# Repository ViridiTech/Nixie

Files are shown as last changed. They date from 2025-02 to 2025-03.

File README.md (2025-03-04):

# Nixie
 4 digit nixie clock on IN-12 lamps
 
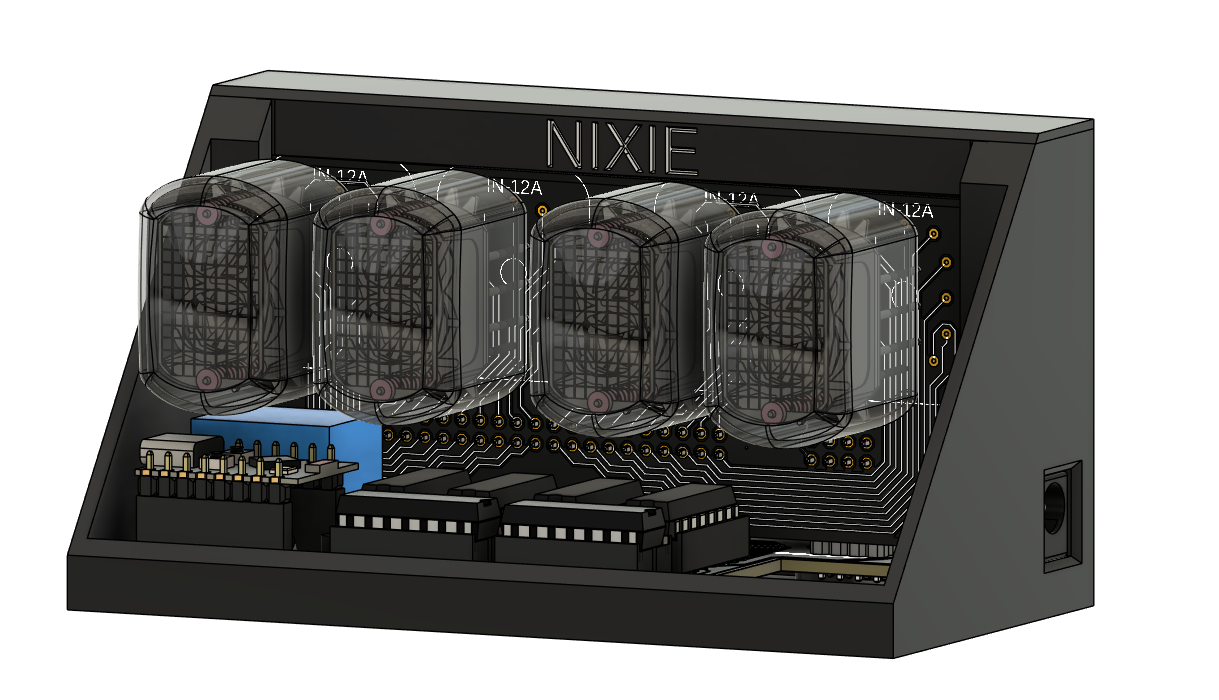
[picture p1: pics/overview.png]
</a>

General schematic inculed most important components:

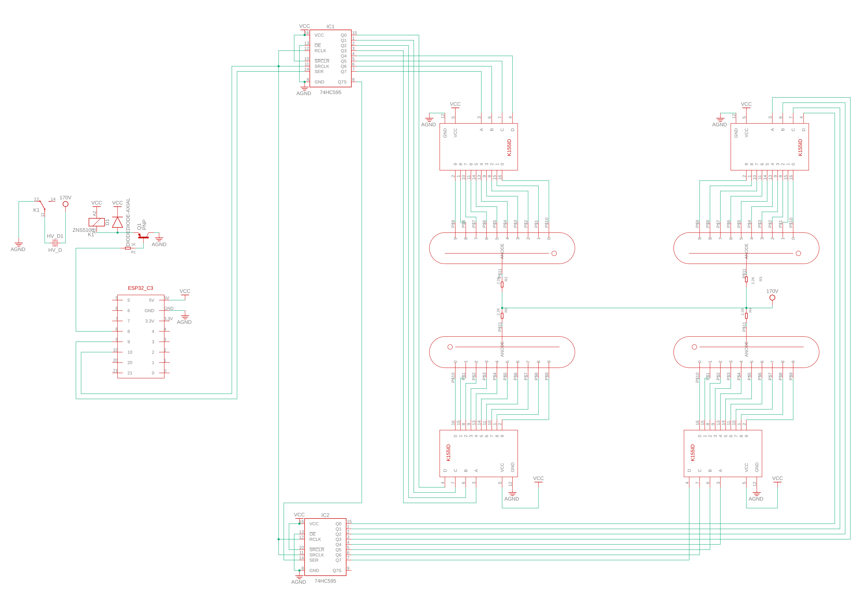
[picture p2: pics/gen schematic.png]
</a>

Brain of the clock is [ESP32-C3 Super Mini](https://allegro.pl/events/clicks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).

ICs used:

- two 74HC959 shift registers,

- four nixie lamp drivers: K155ID1 and SN74141N both work the same and have the same I/O.

Four IN-12 display time. Both A and B variants could be used.

Seconds indicator is taken from probe screwdriver, typical neon indicator (gas-discharge lamp) can be used.

Seconds indicator is driven by 5V relay (transistor-diode control to ensure no damage to microcontroler should be used, or alternatively for DIY solution Arduino relay module can be used).

Nixie lamps require 170V power supply to be used, I chose [this one](https://pl.aliexpress.com/item/1005005721193065.html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).

# IMPORTANT
You have to program ESP32 yourself using Arduino IDE or other ESP-compatible environment using NIXIE_clock directory.

In the code you MUST MODIFY WiFi settings to allow the clock to connect to the Internet.

# DISCLAIMER
The current code has not been tested on current version of hardware.

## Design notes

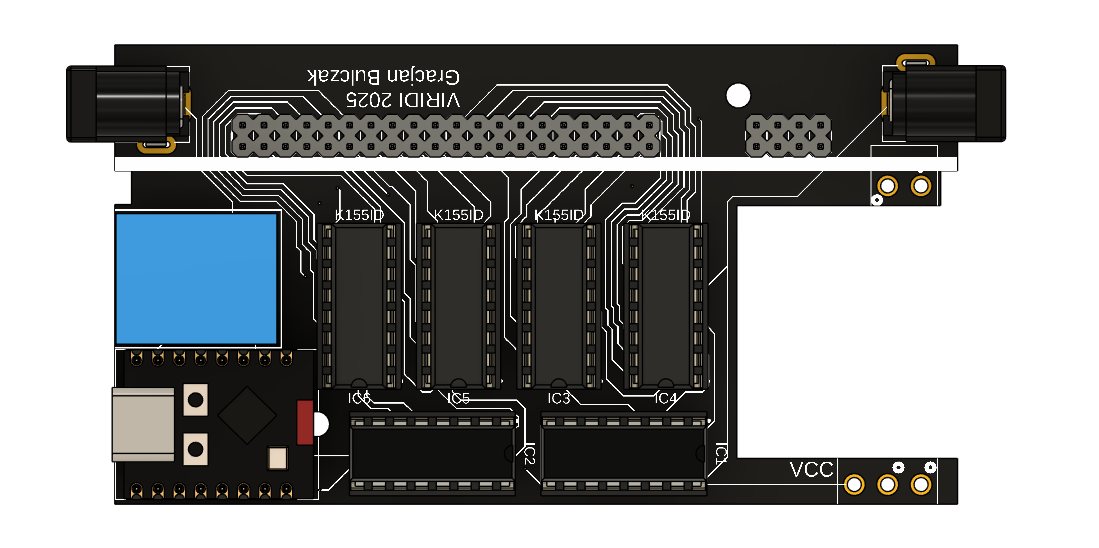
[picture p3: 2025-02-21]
pics/base.png

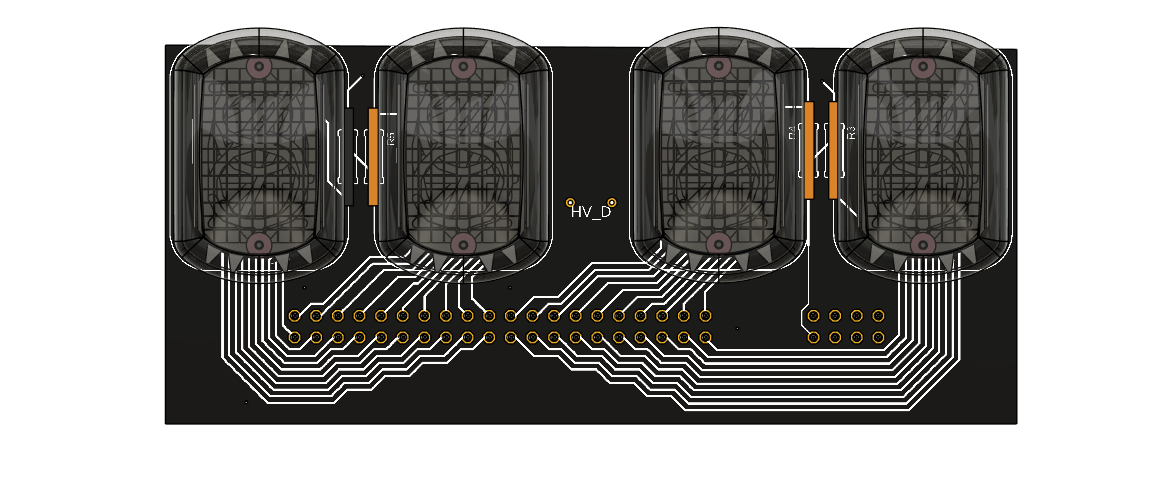
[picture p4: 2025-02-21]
pics/display.png

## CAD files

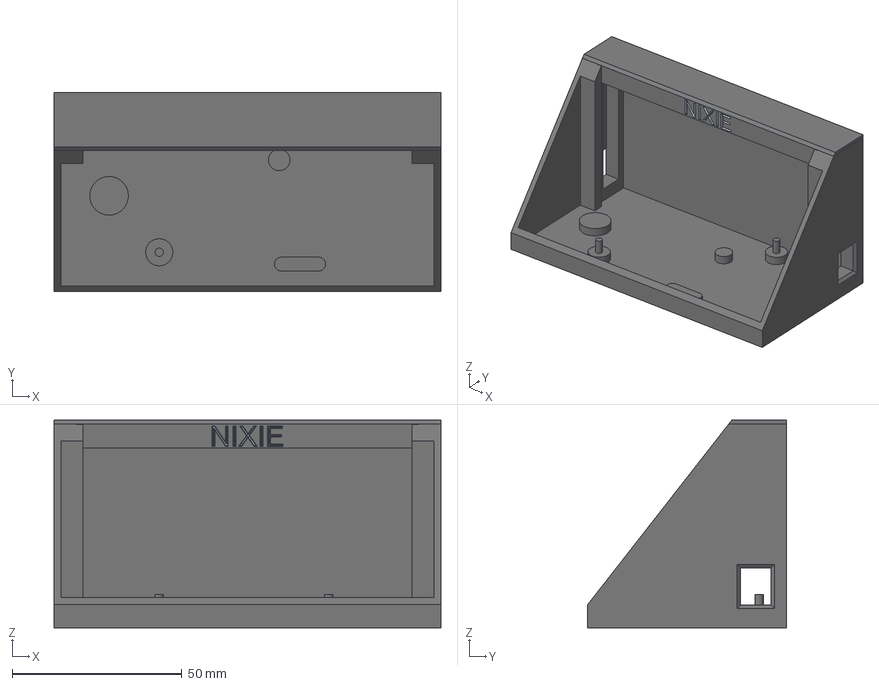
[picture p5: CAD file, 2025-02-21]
Case.3mf
114.0 x 58.5 x 61.2 mm

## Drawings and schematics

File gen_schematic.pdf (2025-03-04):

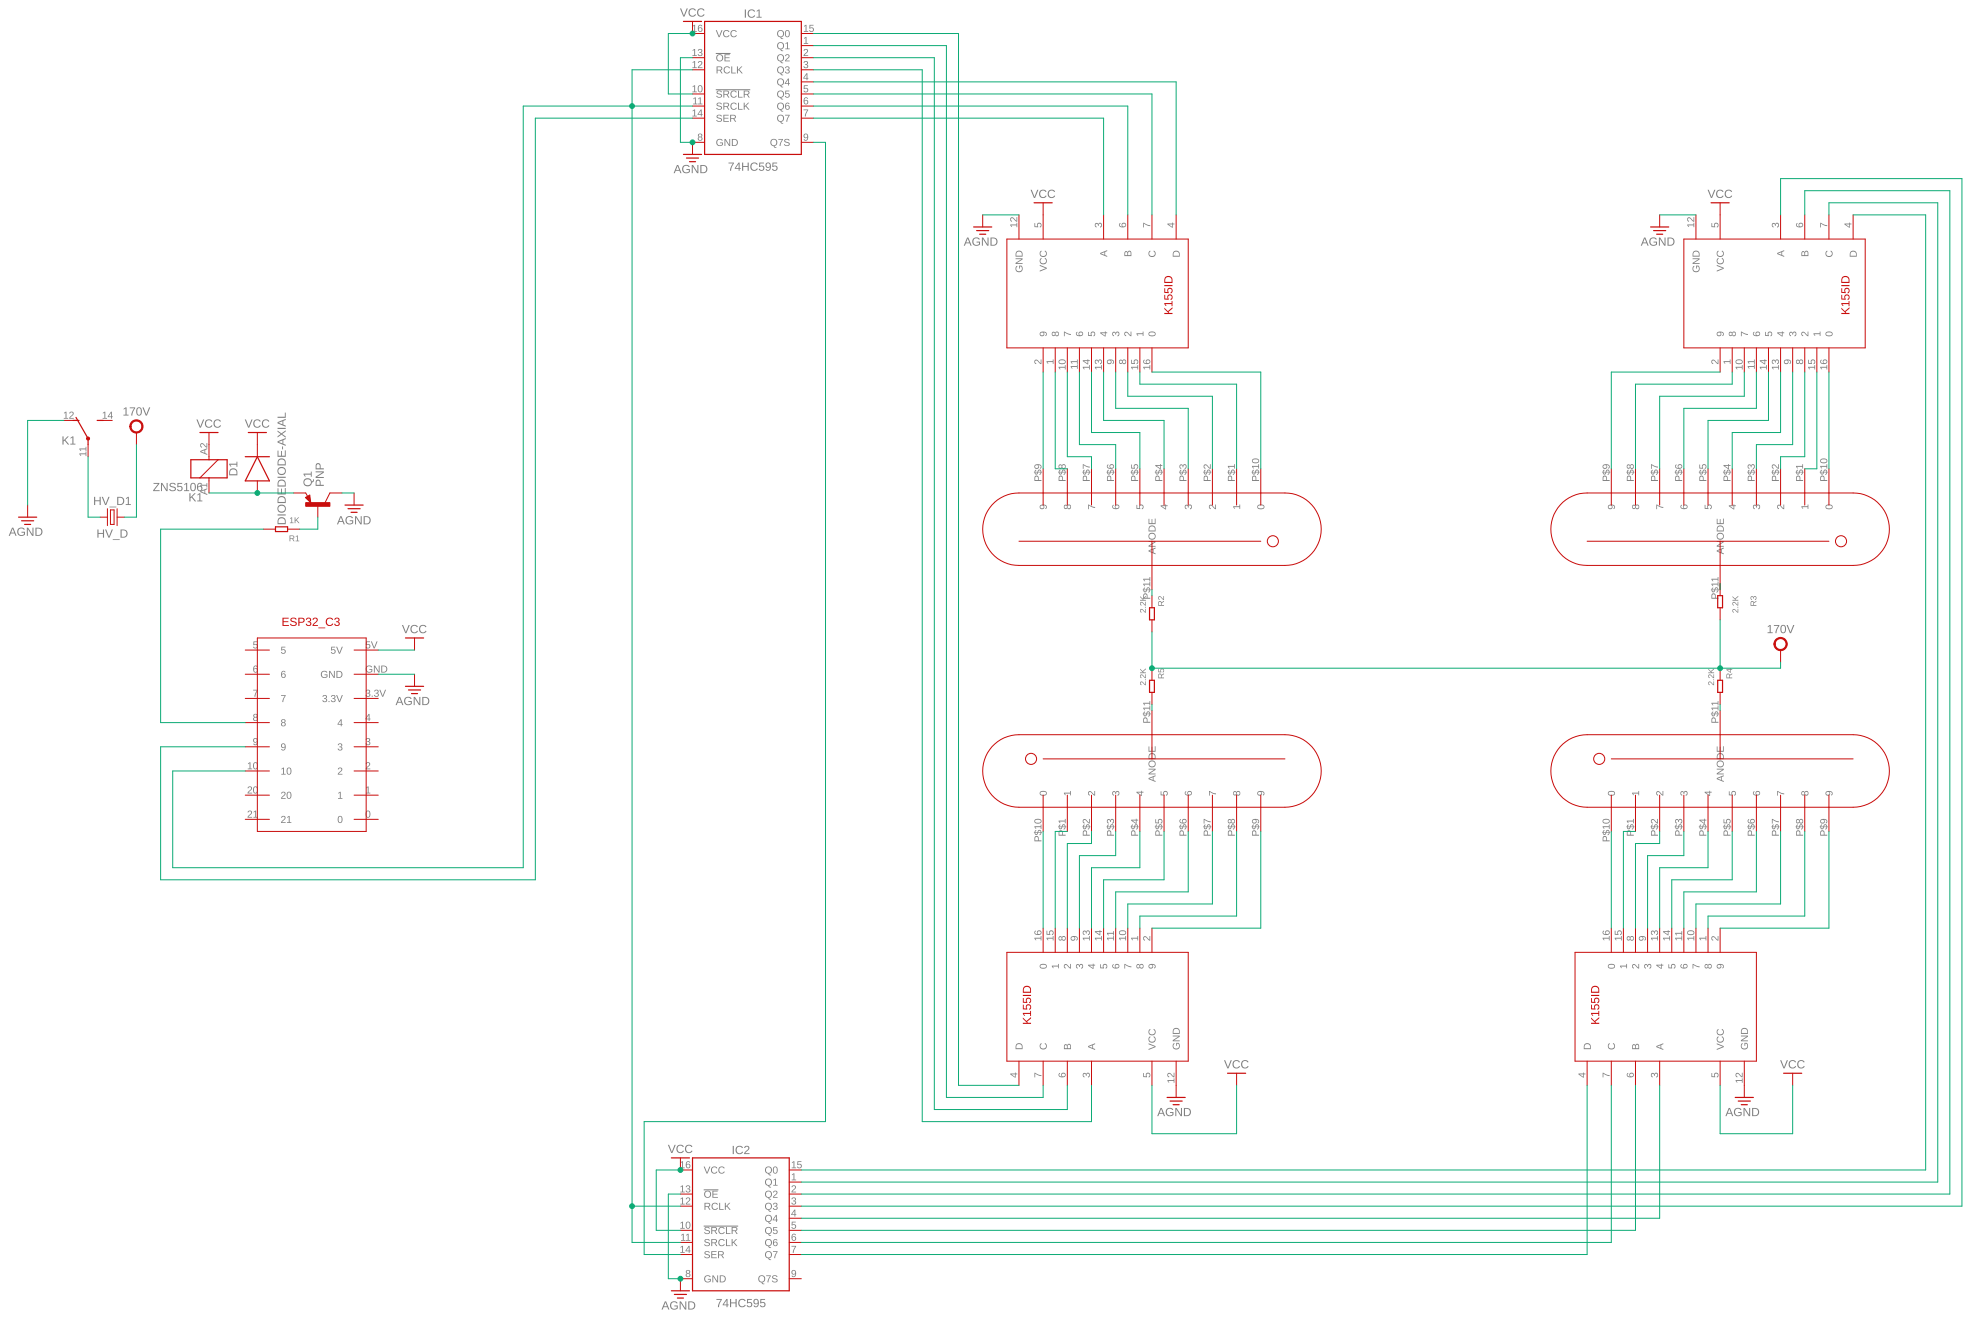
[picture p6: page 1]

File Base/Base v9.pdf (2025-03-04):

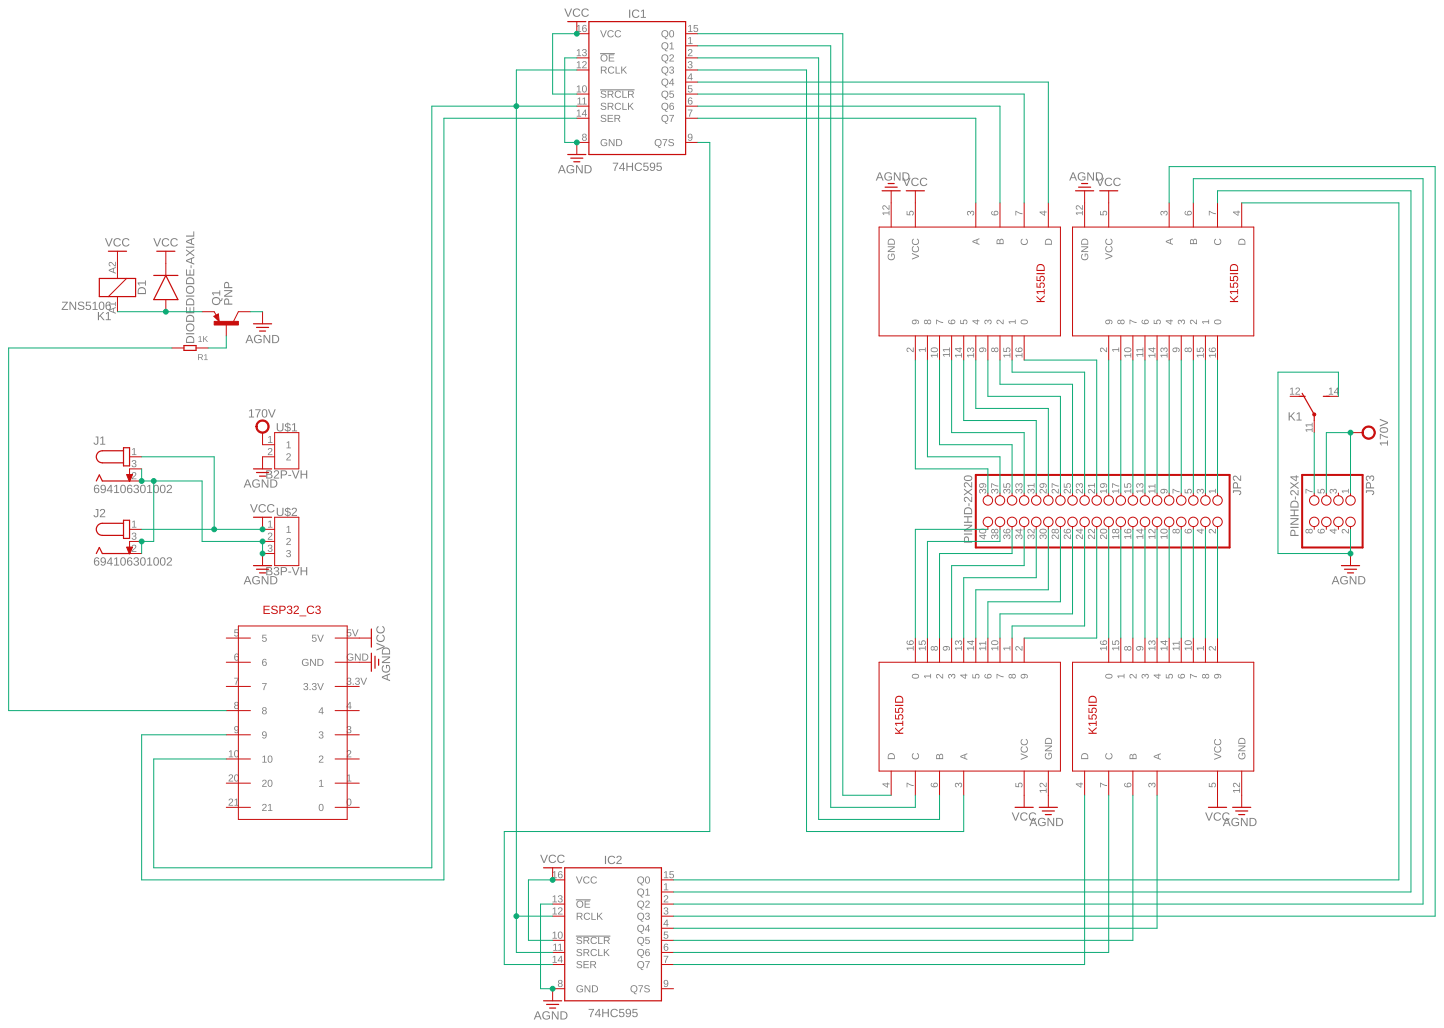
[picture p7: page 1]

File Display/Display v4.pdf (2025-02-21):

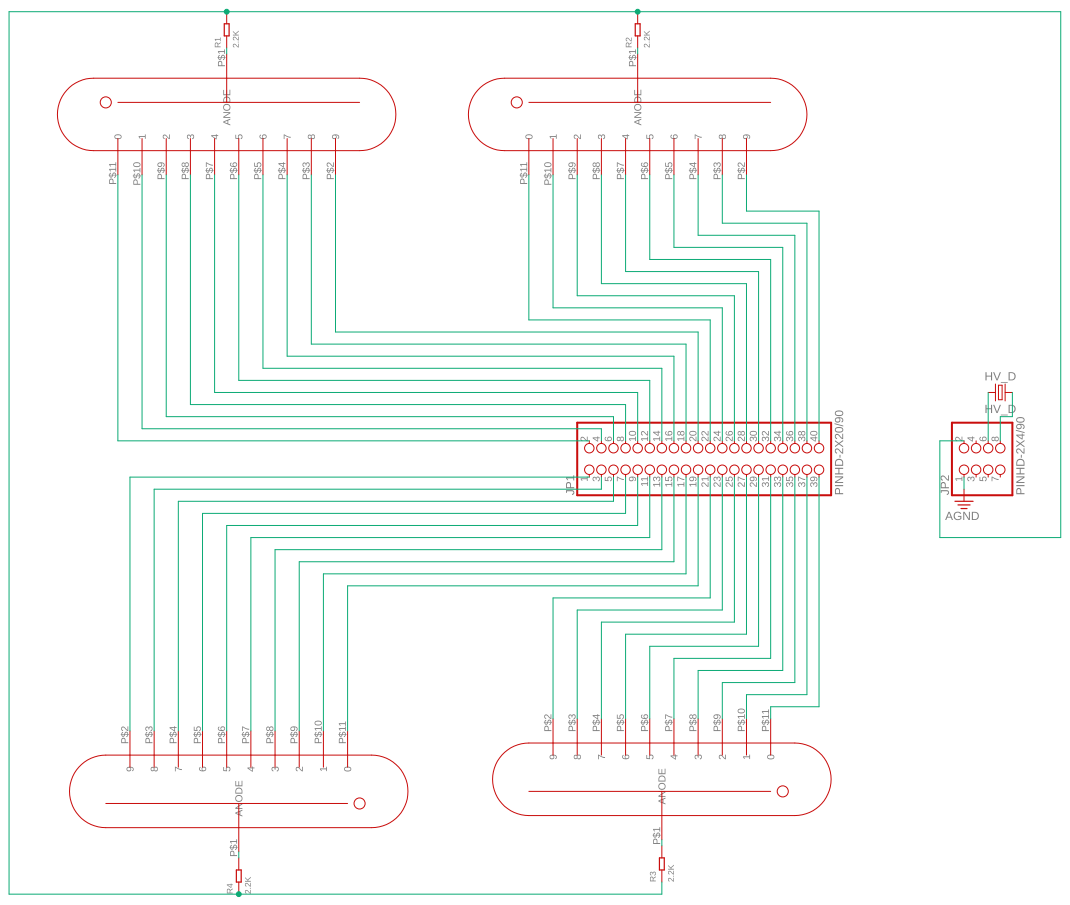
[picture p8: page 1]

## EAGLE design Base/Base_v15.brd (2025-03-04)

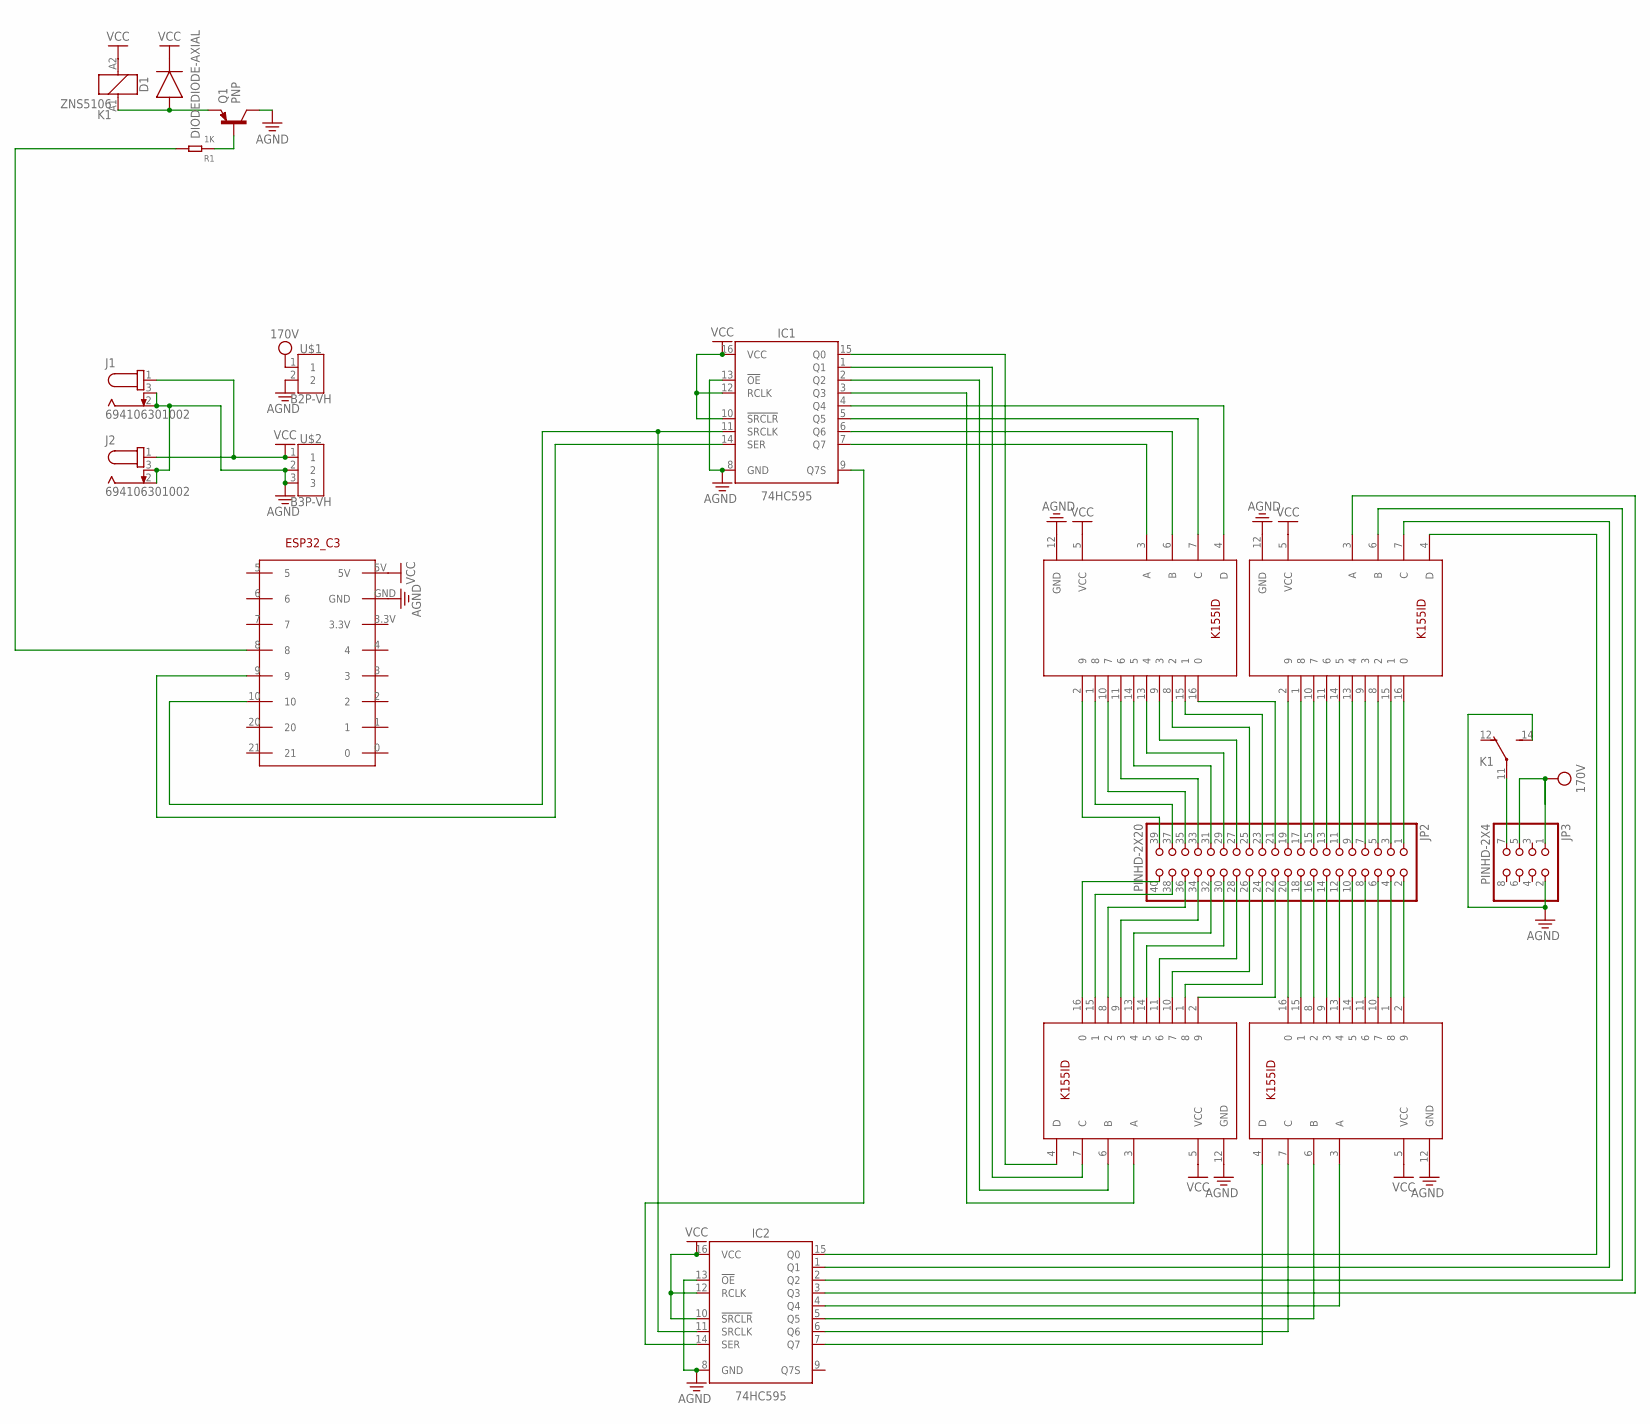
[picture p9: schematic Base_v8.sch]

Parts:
D1: DIODEDIODE-AXIAL; DIODE-AXIAL
IC1, IC2: 74HC595; DIP762W53P254L1969H508Q16B
IC3, IC4, IC5, IC6: K155ID
J1, J2: 694106301002
JP2: PINHD-2X20; 2X20
JP3: PINHD-2X4; 2X04
K1: ZNS5106; ZN5
Q1: PNP; TO92
R1: 1K; PR-D2.3XL6.5MM
U$1: B2P-VH; B2P-VH_396-2N
U$2: B3P-VH; B3P-VH_396_3N
U$5: ESP32_C3_SUPERMINI

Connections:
170V: JP3.1, JP3.5, U$1.1
AGND: IC1.8 (GND), IC1.13 (!OE), IC2.8 (GND), IC2.13 (!OE), IC3.12 (GND), IC4.12 (GND), IC5.12 (GND), IC6.12 (GND), J1.2, J1.3, J2.2, J2.3, JP3.2, K1.14 (S), Q1.1 (C), U$1.2, U$2.2, U$2.3, U$5.GND
unnamed: IC5.16 (0), JP2.1
unnamed: IC5.15 (1), JP2.3
unnamed: IC5.8 (2), JP2.5
unnamed: IC5.9 (3), JP2.7
unnamed: IC5.13 (4), JP2.9
unnamed: IC5.14 (5), JP2.11
unnamed: IC5.11 (6), JP2.13
unnamed: IC5.10 (7), JP2.15
unnamed: IC5.1 (8), JP2.17
unnamed: IC5.2 (9), JP2.19
unnamed: IC3.16 (0), JP2.21
unnamed: IC3.15 (1), JP2.23
unnamed: IC3.8 (2), JP2.25
unnamed: IC3.9 (3), JP2.27
unnamed: IC3.13 (4), JP2.29
unnamed: IC3.14 (5), JP2.31
unnamed: IC3.11 (6), JP2.33
unnamed: IC3.10 (7), JP2.35
unnamed: IC3.1 (8), JP2.37
unnamed: IC3.2 (9), JP2.39
unnamed: IC6.2 (9), JP2.2
unnamed: IC6.1 (8), JP2.4
unnamed: IC6.10 (7), JP2.6
unnamed: IC6.11 (6), JP2.8
unnamed: IC6.14 (5), JP2.10
unnamed: IC6.13 (4), JP2.12
unnamed: IC6.9 (3), JP2.14
unnamed: IC6.8 (2), JP2.16
unnamed: IC6.15 (1), JP2.18
unnamed: IC6.16 (0), JP2.20
unnamed: IC4.16 (0), JP2.40
unnamed: IC4.15 (1), JP2.38
unnamed: IC4.8 (2), JP2.36
unnamed: IC4.9 (3), JP2.34
unnamed: IC4.13 (4), JP2.32
unnamed: IC4.14 (5), JP2.30
unnamed: IC4.11 (6), JP2.28
unnamed: IC4.10 (7), JP2.26
unnamed: IC4.1 (8), JP2.24
unnamed: IC4.2 (9), JP2.22
unnamed: IC1.15 (Q0), IC4.4 (D)
unnamed: IC1.1 (Q1), IC4.7 (C)
unnamed: IC1.2 (Q2), IC4.6 (B)
unnamed: IC1.3 (Q3), IC4.3 (A)
unnamed: IC2.4 (Q4), IC6.3 (A)
unnamed: IC2.5 (Q5), IC6.6 (B)
unnamed: IC2.6 (Q6), IC6.7 (C)
unnamed: IC2.7 (Q7), IC6.4 (D)
unnamed: IC1.7 (Q7), IC3.3 (A)
unnamed: IC1.6 (Q6), IC3.6 (B)
unnamed: IC1.5 (Q5), IC3.7 (C)
unnamed: IC1.4 (Q4), IC3.4 (D)
unnamed: IC2.15 (Q0), IC5.4 (D)
unnamed: IC2.1 (Q1), IC5.7 (C)
unnamed: IC2.2 (Q2), IC5.6 (B)
unnamed: IC2.3 (Q3), IC5.3 (A)
unnamed: IC1.9 (Q7S), IC2.14 (SER)
unnamed: IC1.14 (SER), U$5.9
unnamed: D1.1 (A), K1.A1 (1), Q1.3 (E)
unnamed: Q1.2 (B), R1.1
unnamed: R1.2, U$5.8
unnamed: JP3.7, K1.11

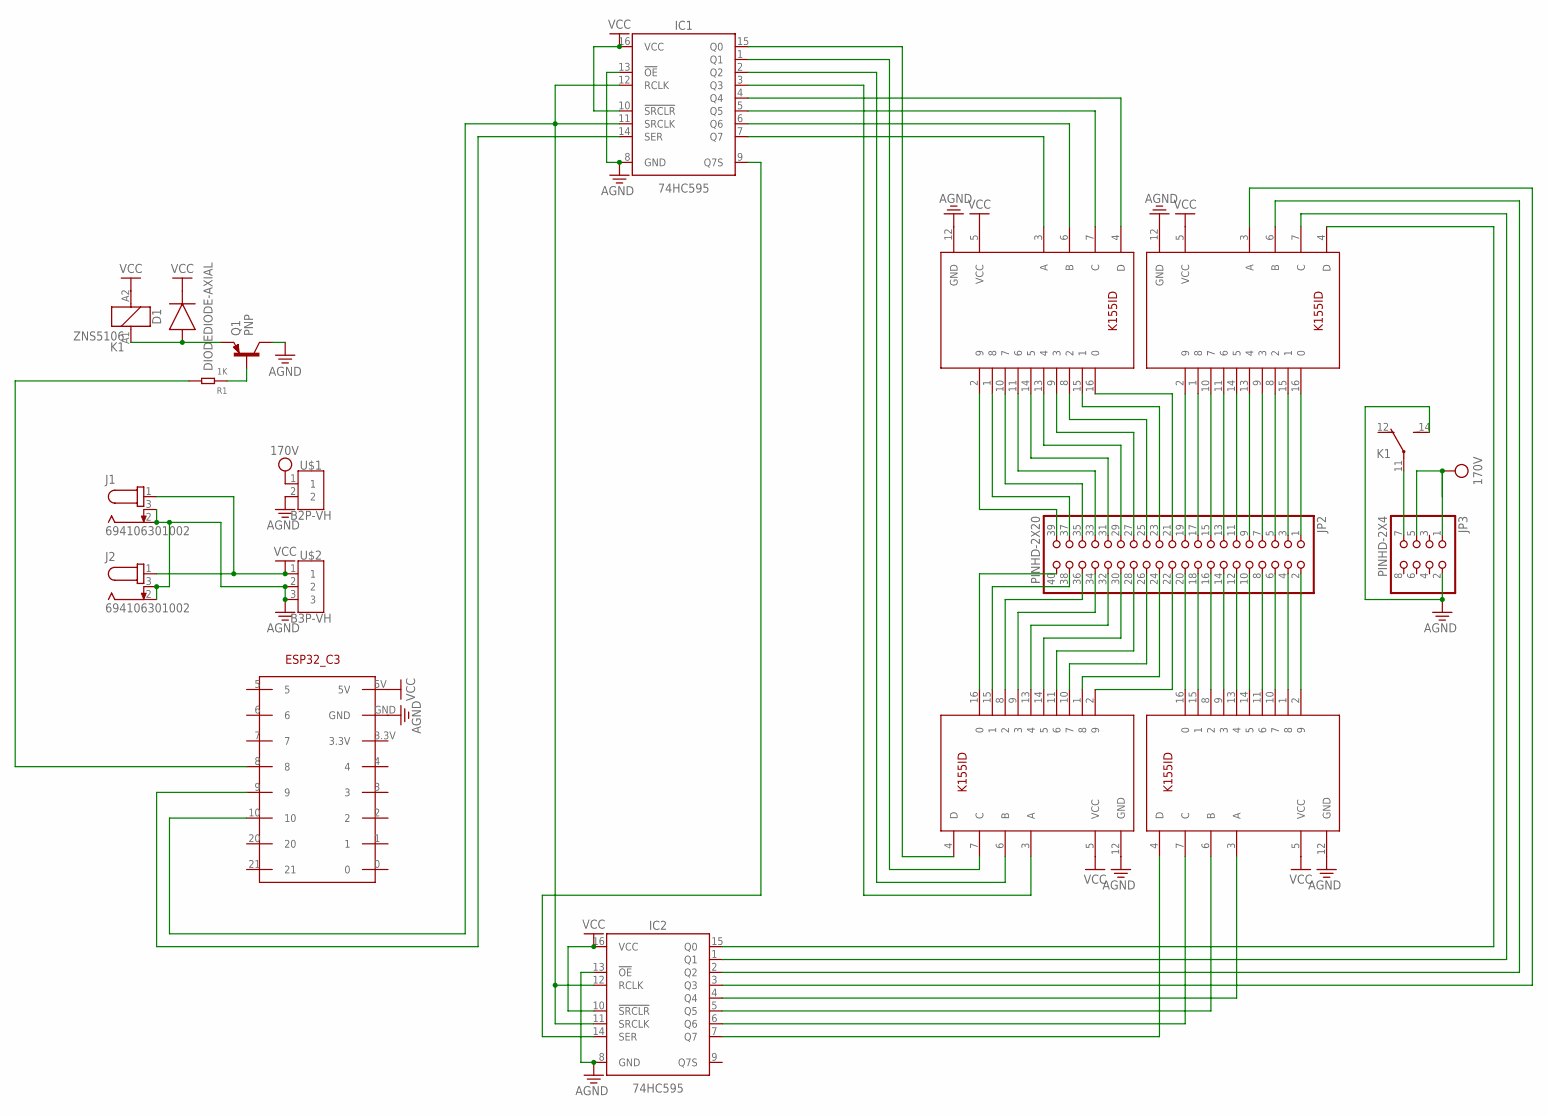
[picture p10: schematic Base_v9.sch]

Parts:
D1: DIODEDIODE-AXIAL; DIODE-AXIAL
IC1, IC2: 74HC595; DIP762W53P254L1969H508Q16B
IC3, IC4, IC5, IC6: K155ID
J1, J2: 694106301002
JP2: PINHD-2X20; 2X20
JP3: PINHD-2X4; 2X04
K1: ZNS5106; ZN5
Q1: PNP; TO92
R1: 1K; PR-D2.3XL6.5MM
U$1: B2P-VH; B2P-VH_396-2N
U$2: B3P-VH; B3P-VH_396_3N
U$5: ESP32_C3_SUPERMINI

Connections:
170V: JP3.1, JP3.5, U$1.1
AGND: IC1.8 (GND), IC1.13 (!OE), IC2.8 (GND), IC2.13 (!OE), IC3.12 (GND), IC4.12 (GND), IC5.12 (GND), IC6.12 (GND), J1.2, J1.3, J2.2, J2.3, JP3.2, K1.14 (S), Q1.1 (C), U$1.2, U$2.2, U$2.3, U$5.GND
unnamed: IC5.16 (0), JP2.1
unnamed: IC5.15 (1), JP2.3
unnamed: IC5.8 (2), JP2.5
unnamed: IC5.9 (3), JP2.7
unnamed: IC5.13 (4), JP2.9
unnamed: IC5.14 (5), JP2.11
unnamed: IC5.11 (6), JP2.13
unnamed: IC5.10 (7), JP2.15
unnamed: IC5.1 (8), JP2.17
unnamed: IC5.2 (9), JP2.19
unnamed: IC3.16 (0), JP2.21
unnamed: IC3.15 (1), JP2.23
unnamed: IC3.8 (2), JP2.25
unnamed: IC3.9 (3), JP2.27
unnamed: IC3.13 (4), JP2.29
unnamed: IC3.14 (5), JP2.31
unnamed: IC3.11 (6), JP2.33
unnamed: IC3.10 (7), JP2.35
unnamed: IC3.1 (8), JP2.37
unnamed: IC3.2 (9), JP2.39
unnamed: IC6.2 (9), JP2.2
unnamed: IC6.1 (8), JP2.4
unnamed: IC6.10 (7), JP2.6
unnamed: IC6.11 (6), JP2.8
unnamed: IC6.14 (5), JP2.10
unnamed: IC6.13 (4), JP2.12
unnamed: IC6.9 (3), JP2.14
unnamed: IC6.8 (2), JP2.16
unnamed: IC6.15 (1), JP2.18
unnamed: IC6.16 (0), JP2.20
unnamed: IC4.16 (0), JP2.40
unnamed: IC4.15 (1), JP2.38
unnamed: IC4.8 (2), JP2.36
unnamed: IC4.9 (3), JP2.34
unnamed: IC4.13 (4), JP2.32
unnamed: IC4.14 (5), JP2.30
unnamed: IC4.11 (6), JP2.28
unnamed: IC4.10 (7), JP2.26
unnamed: IC4.1 (8), JP2.24
unnamed: IC4.2 (9), JP2.22
unnamed: IC1.15 (Q0), IC4.4 (D)
unnamed: IC1.1 (Q1), IC4.7 (C)
unnamed: IC1.2 (Q2), IC4.6 (B)
unnamed: IC1.3 (Q3), IC4.3 (A)
unnamed: IC2.4 (Q4), IC6.3 (A)
unnamed: IC2.5 (Q5), IC6.6 (B)
unnamed: IC2.6 (Q6), IC6.7 (C)
unnamed: IC2.7 (Q7), IC6.4 (D)
unnamed: IC1.7 (Q7), IC3.3 (A)
unnamed: IC1.6 (Q6), IC3.6 (B)
unnamed: IC1.5 (Q5), IC3.7 (C)
unnamed: IC1.4 (Q4), IC3.4 (D)
unnamed: IC2.15 (Q0), IC5.4 (D)
unnamed: IC2.1 (Q1), IC5.7 (C)
unnamed: IC2.2 (Q2), IC5.6 (B)
unnamed: IC2.3 (Q3), IC5.3 (A)
unnamed: IC1.9 (Q7S), IC2.14 (SER)
unnamed: IC1.14 (SER), U$5.9
unnamed: D1.1 (A), K1.A1 (1), Q1.3 (E)
unnamed: Q1.2 (B), R1.1
unnamed: R1.2, U$5.8
unnamed: JP3.7, K1.11

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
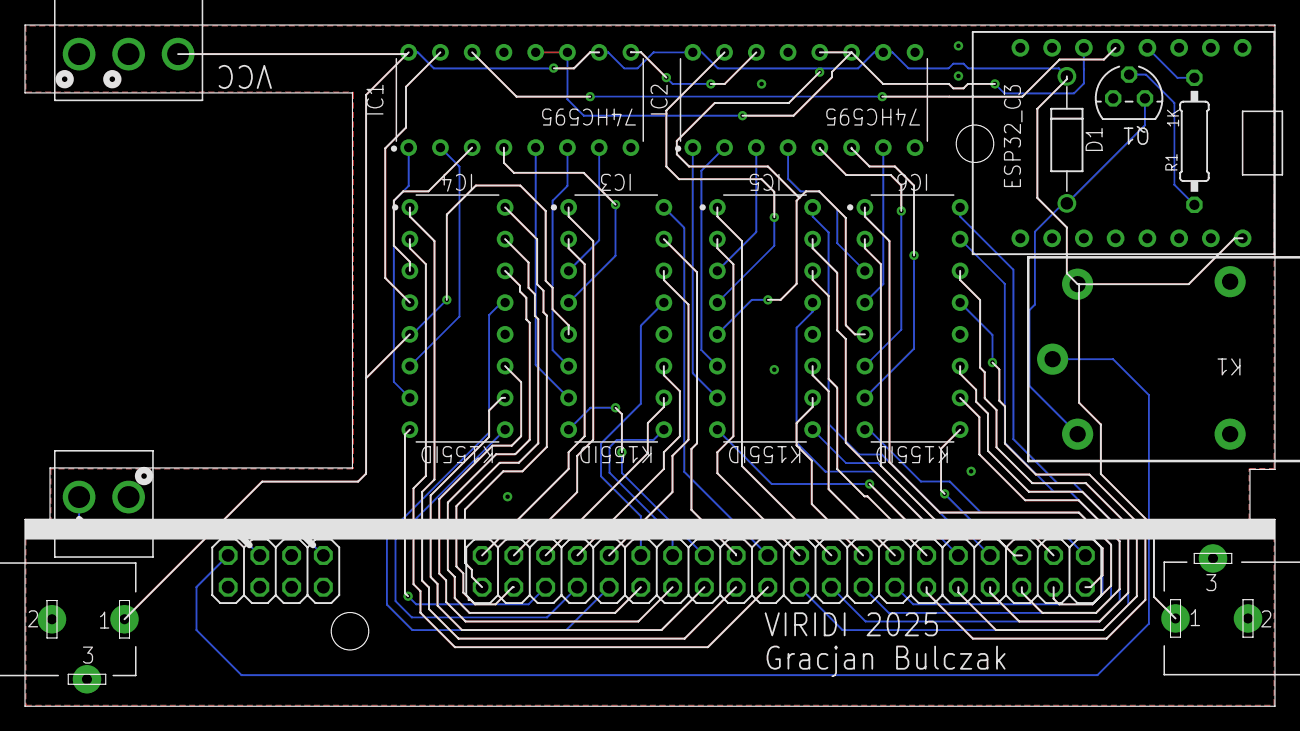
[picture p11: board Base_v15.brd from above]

Board: 2 copper layers, 100.0 x 54.5 mm, 17 parts (0 on the bottom side), 66 nets.

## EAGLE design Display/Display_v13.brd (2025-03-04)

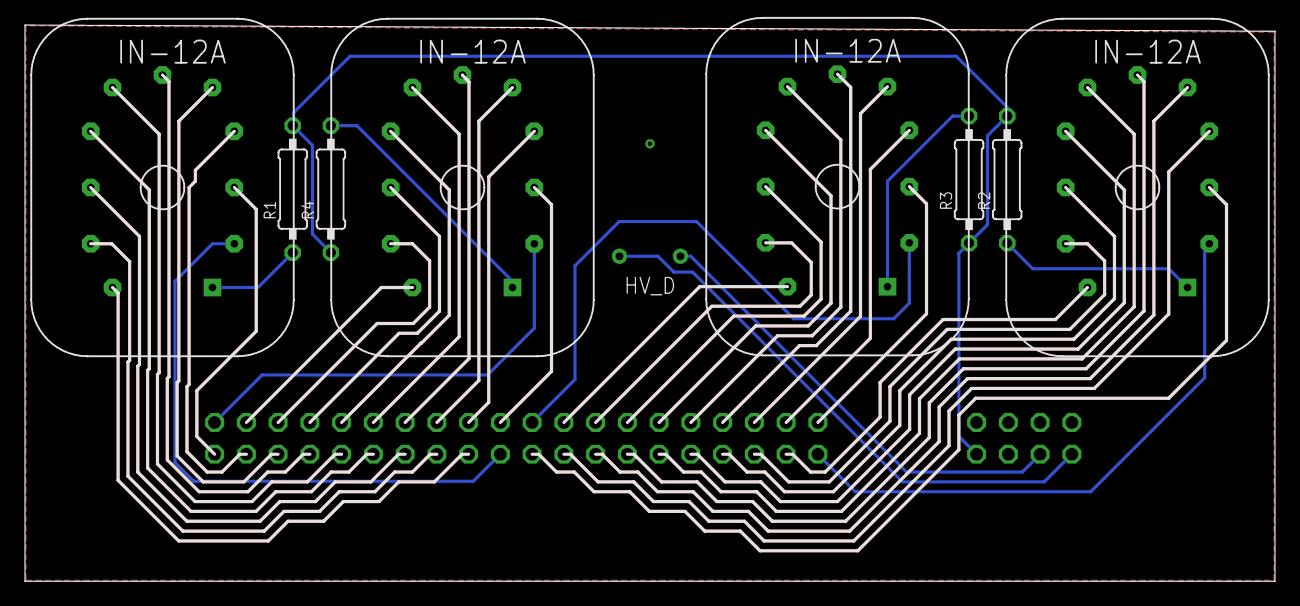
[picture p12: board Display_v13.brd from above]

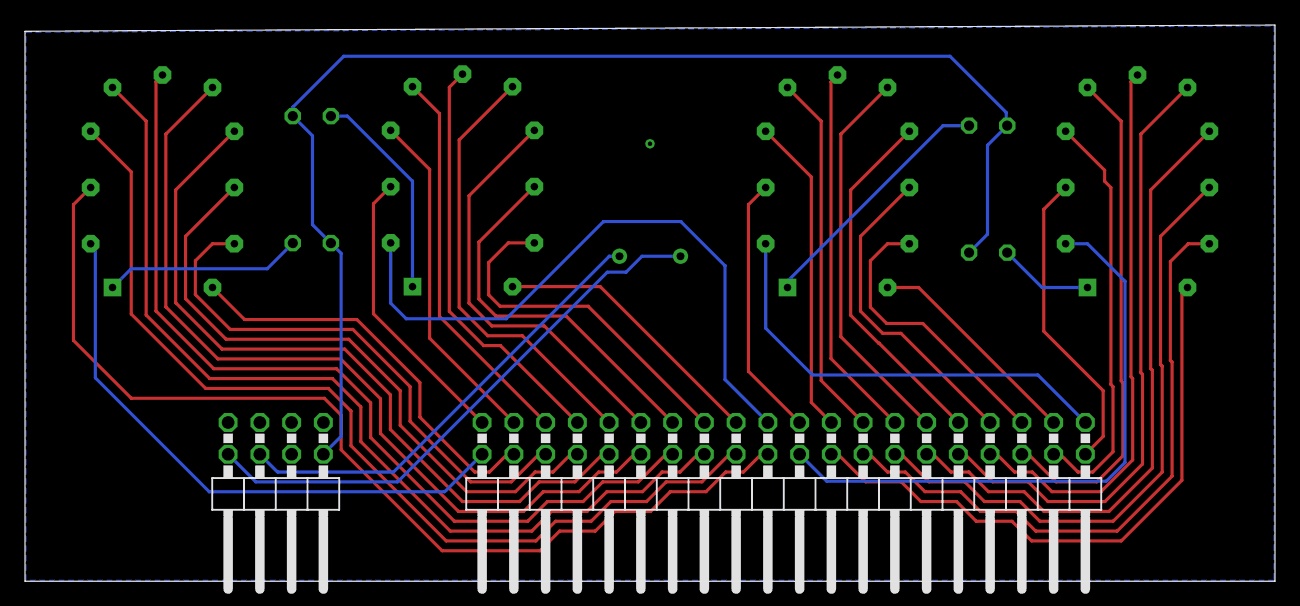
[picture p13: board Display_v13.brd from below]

Board: 2 copper layers, 100.0 x 44.5 mm, 11 parts (2 on the bottom side), 47 nets.

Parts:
HV_D: HV_D; XTALRR488W43L1135T465H1346B
JP1: PINHD-2X20/90; 2X20/90
JP2: PINHD-2X4/90; 2X04/90
R1, R2, R3, R4: 2.2K; PR-D2.3XL6.5MM
U$1, U$2, U$3, U$4: IN-12

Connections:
unnamed: JP1.23, U$4.P$1
unnamed: JP1.39, U$4.P$9
unnamed: JP1.4, U$1.P$8
unnamed: JP1.6, U$1.P$7
unnamed: JP1.40, U$2.P$10
unnamed: JP1.22, U$2.P$9
unnamed: JP1.19, U$3.P$9
unnamed: JP1.17, U$3.P$8
unnamed: JP1.15, U$3.P$7
unnamed: JP1.13, U$3.P$6
unnamed: JP1.11, U$3.P$5
unnamed: JP1.9, U$3.P$4
unnamed: JP1.7, U$3.P$3
unnamed: JP1.5, U$3.P$2
unnamed: JP1.3, U$3.P$1
unnamed: JP1.1, U$3.P$10
unnamed: HV_D.2, JP2.8
unnamed: HV_D.1, JP2.6
unnamed: JP1.14, U$1.P$3
unnamed: JP1.16, U$1.P$2
unnamed: R1.1, U$1.P$11
unnamed: R2.1, U$2.P$11
unnamed: R3.2, U$4.P$11
unnamed: R4.2, U$3.P$11
unnamed: JP2.2, R1.2, R2.2, R3.1, R4.1
unnamed: JP1.18, U$1.P$1
unnamed: JP1.20, U$1.P$10
unnamed: JP1.38, U$2.P$1
unnamed: JP1.36, U$2.P$2
unnamed: JP1.34, U$2.P$3
unnamed: JP1.24, U$2.P$8
unnamed: JP1.26, U$2.P$7
unnamed: JP1.28, U$2.P$6
unnamed: JP1.30, U$2.P$5
unnamed: JP1.32, U$2.P$4
unnamed: JP1.2, U$1.P$9
unnamed: JP1.8, U$1.P$6
unnamed: JP1.10, U$1.P$5
unnamed: JP1.12, U$1.P$4
unnamed: JP1.37, U$4.P$8
unnamed: JP1.35, U$4.P$7
unnamed: JP1.33, U$4.P$6
unnamed: JP1.31, U$4.P$5
unnamed: JP1.29, U$4.P$4
unnamed: JP1.27, U$4.P$3
unnamed: JP1.25, U$4.P$2
unnamed: JP1.21, U$4.P$10

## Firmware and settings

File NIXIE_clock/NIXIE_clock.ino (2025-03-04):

#include <WiFi.h>
#include "time.h"
#include "esp_sntp.h"


// Your WiFi settings for clock to synchronize with global server
const char *ssid = "YOUR_SSID";
const char *password = "YOUR_PASSCODE";

const char *ntpServer1 = "pool.ntp.org";
const char *ntpServer2 = "time.nist.gov";
const long gmtOffset_sec = 3600;
const int daylightOffset_sec = 3600;

const char *time_zone = "CET-1CEST,M3.5.0,M10.5.0/3";

// Pin configuration
const int PIN_LAMP = 7;
const int PIN_RELAY = 8;
const int PIN_DATA = 9;
const int PIN_CLOCK = 10;

// Delay time influences time change animation speed (minimum 8)
const int DELAY_TIME = 15;

// State variables
bool RELAY = false;
int number = -1;
int previousTime = -1;
int previousSec = -1;
unsigned long now = 0;

// Binary decoding (if numbers are not displayed or are switched in your case, you have different nixie tubes pinout, change these tables according to your datasheet)
bool key[10][4] = {
  { 0, 0, 0, 0 }, { 0, 0, 0, 1 }, { 0, 0, 1, 0 }, { 0, 0, 1, 1 }, { 0, 1, 0, 0 }, { 0, 1, 0, 1 }, { 0, 1, 1, 0 }, { 0, 1, 1, 1 }, { 1, 0, 0, 0 }, { 1, 0, 0, 1 }
};

// Display a number on a specific lamp
void display(int number) {
  if (number < 0 || number >= 10) return;  // Validate input

  for (int i = 0; i < 4; i++) {
    step(key[number][i]);
  }
}


void step(bool dataState) {
  digitalWrite(PIN_DATA, dataState);
  delay(DELAY_TIME);
  digitalWrite(PIN_CLOCK, HIGH);
  delay(DELAY_TIME);
  digitalWrite(PIN_CLOCK, LOW);
}


//Print time on a clock
void printLocalTime() {
  static unsigned long lastUpdateMillis = 0;  // Last time the function ran
  const unsigned long interval = 1000;        // 1 second interval

  // Ensure this function runs at most once per second
  if (millis() - lastUpdateMillis < interval) {
    return;
  }
  lastUpdateMillis = millis();

  struct tm timeinfo;
  if (!getLocalTime(&timeinfo)) {
    return;
  }

  // Update the display if the minute changes
  if (previousTime != timeinfo.tm_min) {
    for (int j = 0; j < 4; j++) {
      switch (j) {
        case 0:
          number = timeinfo.tm_hour / 10;
          break;
        case 1:
          number = timeinfo.tm_hour % 10;
          break;
        case 2:
          number = timeinfo.tm_min / 10;
          break;
        case 3:
          number = timeinfo.tm_min % 10;
          break;
      }
      display(number);
    }
    step(0);
    previousTime = timeinfo.tm_min;
  }
}



void timeavailable(struct timeval *t) {
  printLocalTime();
}

void setup() {

  pinMode(PIN_LAMP, OUTPUT);
  pinMode(PIN_RELAY, OUTPUT);
  pinMode(PIN_DATA, OUTPUT);
  pinMode(PIN_CLOCK, OUTPUT);

  digitalWrite(PIN_RELAY, RELAY);

  WiFi.begin(ssid, password);
  WiFi.setTxPower(WIFI_POWER_8_5dBm);

  esp_sntp_servermode_dhcp(1);  // (optional)

  while (WiFi.status() != WL_CONNECTED) {
    delay(500);
  }

  sntp_set_time_sync_notification_cb(timeavailable);

  configTime(gmtOffset_sec, daylightOffset_sec, ntpServer1, ntpServer2);
}

void loop() {
  if (millis() >= now + 1000) {
    now = millis();
    digitalWrite(PIN_RELAY, RELAY);
    RELAY = !RELAY;
    printLocalTime();
  }
}

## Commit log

2025-02-21 bulk upload
    [Base v14.brd, Base_v8.sch, Display v12.brd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]
2025-02-21 STEP file and 3D manufacturing file upload
    [Case.3mf]
2025-03-04 Resolved switched pins issue
    [Display v12.brd, Display_v13.brd, Display_v5.sch]
2025-03-04 Added general schematic for DIY makers
2025-03-04 Fixed shift register clock lines
    [Base_v15.brd, Base_v9.sch]
2025-03-04 Create gen schematic.png
2025-03-04 General schematic for DIY makers
2025-03-04 Added ESP32 program [.ino]
